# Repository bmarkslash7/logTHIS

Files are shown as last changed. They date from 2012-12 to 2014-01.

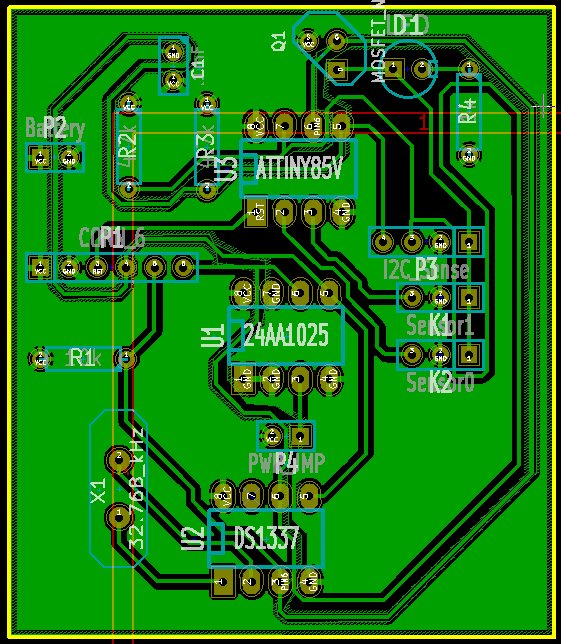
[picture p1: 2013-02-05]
schematic/logTHIS_pcb.jpg

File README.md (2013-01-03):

logTHIS
=======

Schematics and code for logTHIS, a low-powered datalogger for Temperature, Humidity and Irradiance Sensors.

Christopher Stieha: stieha at hotmail dot com

Abram Connelly: abetusk at gmail dot com

We are debating the CERN Open Hardware 1.1 licence (see ohwr.org/projects/cernohl/wiki) or the Creative Commons Attribution Share-Alike license (ala Arduino).

0------------------------------------------------

I2C functions are from http://www.instructables.com/id/I2C_Bus_for_ATtiny_and_ATmega/

0------------------------------------------------

The temperature and humidity sensor code is licensed under the GNU Lesser General Public License version 2.1.  
We stripped down the code available at http://nethoncho.com/arduino/DHT22/

From nethoncho.com:
  DHT22.cpp - DHT22 sensor library
  Developed by Ben Adams - 2011

  This library is free software; you can redistribute it and/or
  modify it under the terms of the GNU Lesser General Public
  License as published by the Free Software Foundation; either
  version 2.1 of the License, or (at your option) any later version.

  This library is distributed in the hope that it will be useful,
  but WITHOUT ANY WARRANTY; without even the implied warranty of
  MERCHANTABILITY or FITNESS FOR A PARTICULAR PURPOSE.  See the GNU
  Lesser General Public License for more details.

  You should have received a copy of the GNU Lesser General Public
  License along with this library; if not, write to the Free Software
  Foundation, Inc., 51 Franklin St, Fifth Floor, Boston, MA  02110-1301  USA

0------------------------------------------------

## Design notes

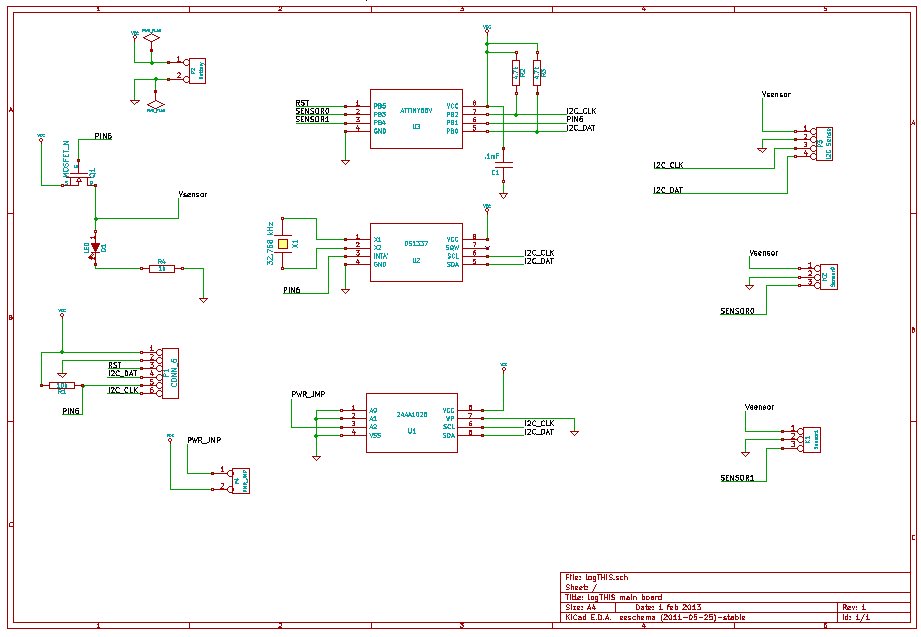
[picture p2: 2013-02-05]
schematic/logTHIS_schematic.jpg

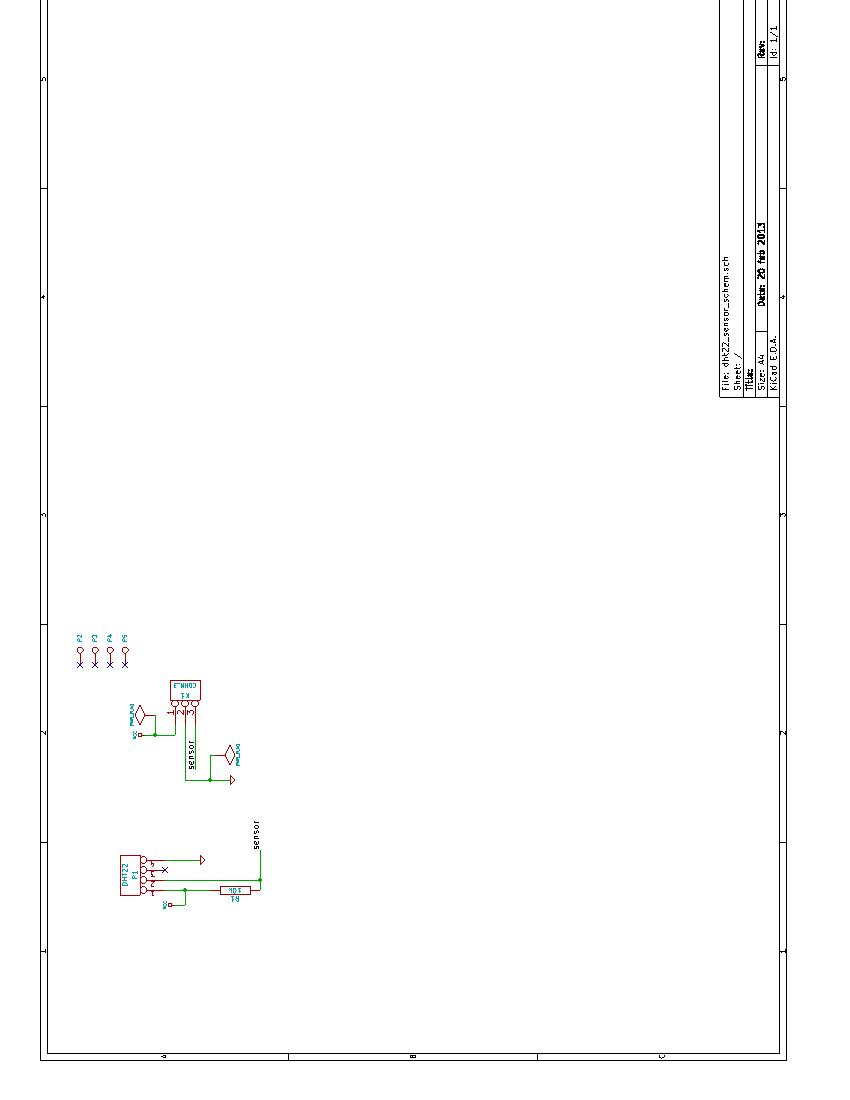
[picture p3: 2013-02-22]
pcb/dht22_sensor_schem/dht22_sensor_schematic.jpg

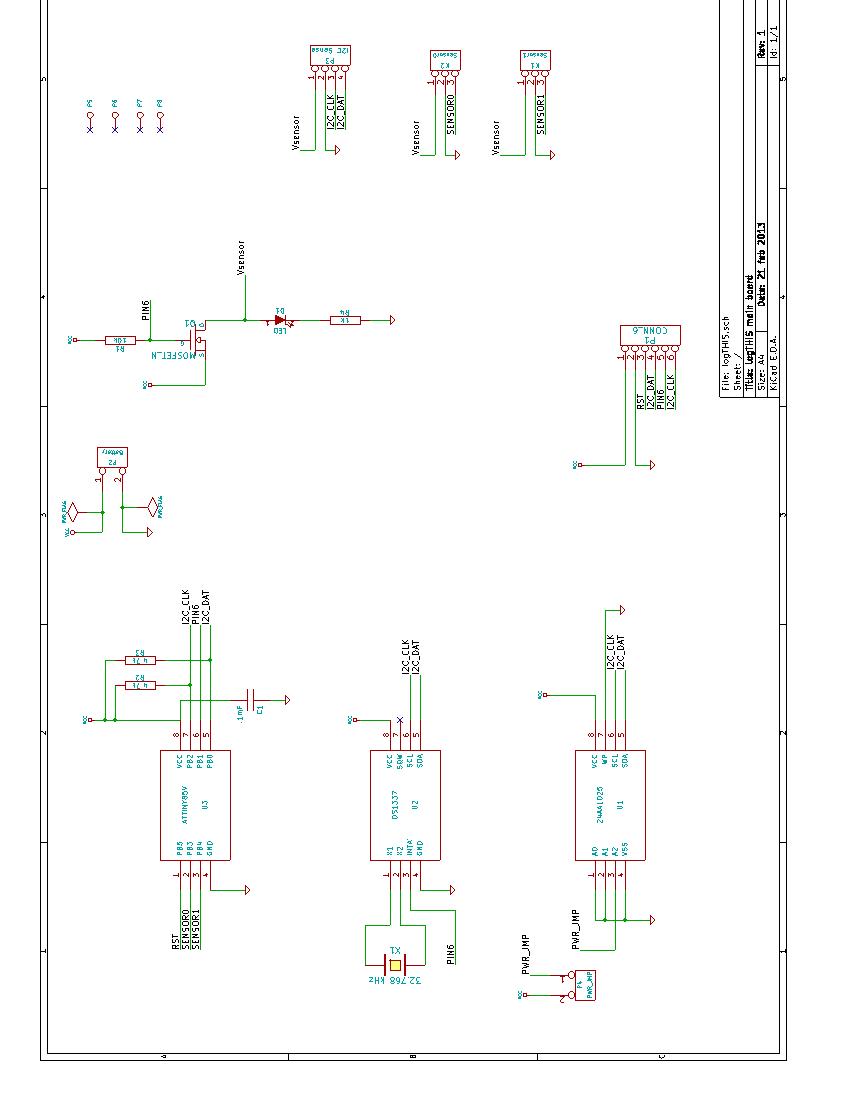
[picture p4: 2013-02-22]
pcb/logTHIS/logTHIS_schematic.jpg

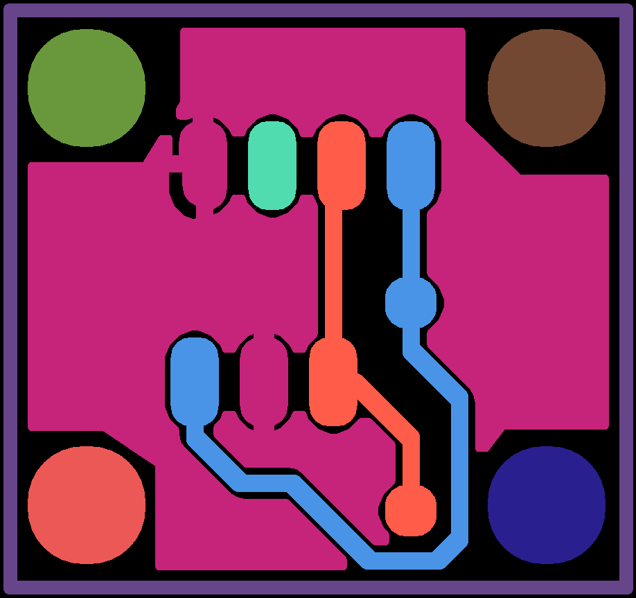
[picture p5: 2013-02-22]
pcb/gcode/dht22_sensor_schem/outp2_traced.png

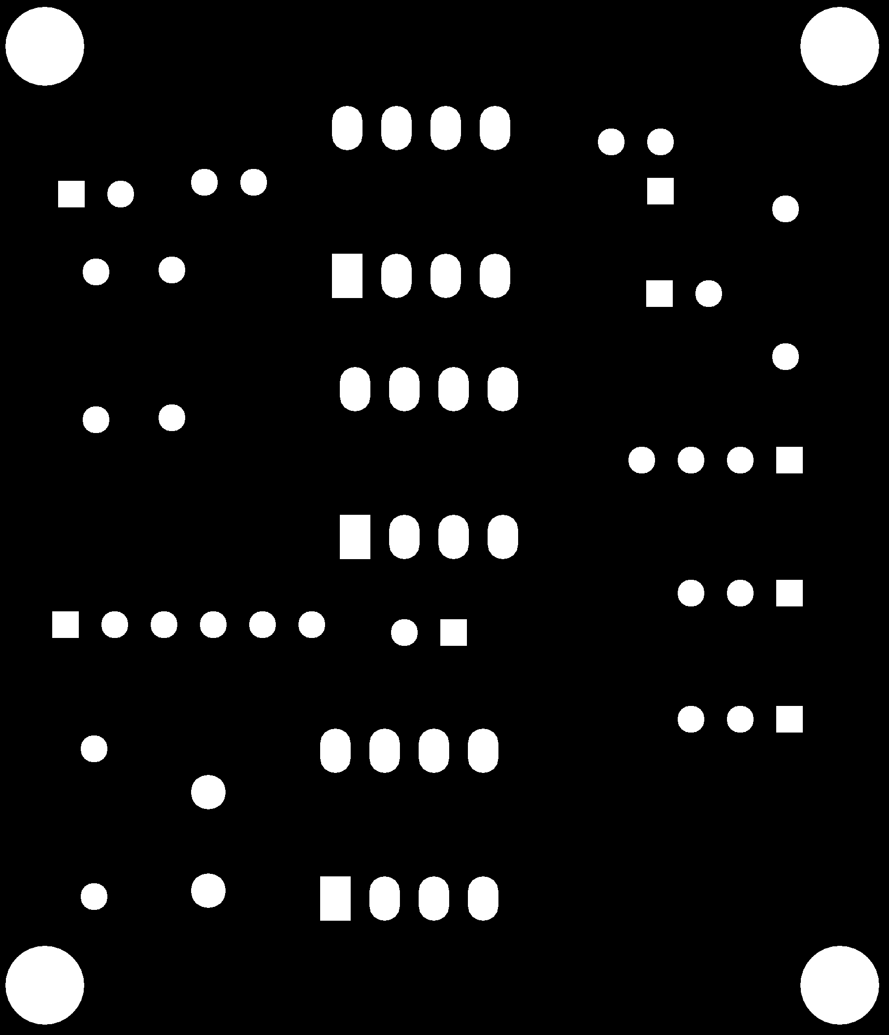
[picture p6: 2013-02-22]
pcb/gcode/logTHIS/outp1_original_front.png

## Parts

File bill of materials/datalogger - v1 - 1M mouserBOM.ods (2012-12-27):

mouser part number | quantity 1 | Mfg Part Number | Mfg Name | Mouser Part Number | Description | Price 1 | Min\Mult | Stock | Lead Time | Lifecycle | NCNR | RoHS | Suggested Replacement | RoHS Replacement | PB Free | Package Type | Package Quantity | Package Price | Data Sheet URL | Product Image
556-ATTINY85V10PU | 1 | ATTINY85V-10PU | Atmel | 556-ATTINY85V10PU | 8-bit Microcontrollers - MCU 8-bit Microcontrollers - MCU 8kB Flash 0.512kB EEPROM 6 I/O Pins | $2.26 | 1\1 | 2,355 | 6 Weeks |  | No | Yes
700-DS1337 | 1 | DS1337+ | Maxim Integrated | 700-DS1337 | Real Time Clock Real Time Clock I2C Serial RTC | $2.58 | 1\1 | 132 | 3 Weeks |  | No | Yes
579-24AA1025-I/P | 1 | 24AA1025-I/P | Microchip | 579-24AA1025-I/P | EEPROM EEPROM 1M | $3.65 | 1\1 | 106 |  |  |  | Yes
579-24AA32A-I/P | 1 | 24AA32A-I/P | Microchip | 579-24AA32A-I/P | EEPROM EEPROM 4kx8 | $0.50 | 1\1 | 918 |  |  | No | Yes
522-ZVP3306A | 1 | ZVP3306A | Diodes Inc. | 522-ZVP3306A | MOSFET MOSFET P-Chnl 60V | $0.64 | 1\1 | 3,572 |  |  | No | Yes
732-C002RX32.76K-EPB | 1 | C-002RX 32.7680K-E:PBFREE | Epson | 732-C002RX32.76K-EPB | Crystals Crystals 32.768KHz 6.0pF 20ppm -10C +60C | $0.32 | 1\1 | 6,623 | 6 Weeks |  | No | Yes

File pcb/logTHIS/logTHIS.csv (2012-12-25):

Id | Designator | Package | Quantity | Designation | Supplier and ref
1 | Q1 | TO92DGS | 1 | MOSFET_N
2 | P1 | SIL-6 | 1 | CONN_6
3 | P3 | SIL-4 | 1 | I2C_Sense
4 | K2 | SIL-3 | 1 | Sensor0
5 | K1 | SIL-3 | 1 | Sensor1
6 | P2 | SIL-2 | 1 | Battery
7 | D1 | LEDV | 1 | LED
8 | U3 | DIP-8__300_ELL | 1 | ATTINY85V
9 | U1 | DIP-8__300_ELL | 1 | 24AA1025
10 | U2 | DIP-8__300_ELL | 1 | DS1337
11 | C1 | C1 | 1 | .1mF
12 | R1 | R3 | 1 | 10k
13 | R2,R3 | R3 | 2 | 4.7k
14 | R4 | R3 | 1 | 1k
15 | X1 | HC-18UV | 1 | 32.768_kHz

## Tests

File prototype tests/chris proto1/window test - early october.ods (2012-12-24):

 |  | light1 |  |  | light2 |  |  | temp |  |  | humidity |  | time(backwards) | time(backwards)
0 | 14CA | 5322 | 2 | 498 | 1176 | 4 | CA | 202 | 6 | 222 | 546 | 8 | 2 | 2
10 | 9AB | 2475 | 12 | 21A | 538 | 14 | CD | 205 | 16 | 229 | 553 | 18 | 3002 | 12290
20 | 2A8 | 680 | 22 | 96 | 150 | 24 | DB | 219 | 26 | 212 | 530 | 28 | 3 | 3
30 | 458 | 1112 | 32 | EF | 239 | 34 | E9 | 233 | 36 | 1F7 | 503 | 38 | 3003 | 12291
40 | 4D1 | 1233 | 42 | 106 | 262 | 44 | F3 | 243 | 46 | 1E3 | 483 | 48 | 4 | 4
50 | 88D | 2189 | 52 | 1DE | 478 | 54 | F6 | 246 | 56 | 1EE | 494 | 58 | 3004 | 12292
60 | F2F | 3887 | 62 | 34F | 847 | 64 | F3 | 243 | 66 | 1FF | 511 | 68 | 5 | 5
70 | C83 | 3203 | 72 | 2C1 | 705 | 74 | EF | 239 | 76 | 1FF | 511 | 78 | 3005 | 12293
80 | 5F5 | 1525 | 82 | 14A | 330 | 84 | EF | 239 | 86 | 1F5 | 501 | 88 | 6 | 6
90 | 9BA | 2490 | 92 | 21C | 540 | 94 | F2 | 242 | 96 | 1EB | 491 | 98 | 3006 | 12294
100 | 990 | 2448 | 102 | 214 | 532 | 104 | F1 | 241 | 106 | 1EC | 492 | 108 | 7 | 7
110 | 931 | 2353 | 112 | 203 | 515 | 114 | F1 | 241 | 116 | 1F2 | 498 | 118 | 3007 | 12295
120 | 138A | 5002 | 122 | 456 | 1110 | 124 | EF | 239 | 126 | 1FF | 511 | 128 | 8 | 8
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

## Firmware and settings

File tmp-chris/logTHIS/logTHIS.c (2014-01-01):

/*********************************************
ver2 of datalogger:
Wake up from alarm from RTC once a minute
Determine whether uC needs to collect data
Read from Humidity sensor (keep trying a couple of times if initial fails
Read from Light sensor - convert cap sensor to ADC
Write data to EEPROM
Put AVR to sleep
 * Author: christopher stieha
 * Filename: logTHIS.c
 * Chip: ATtiny85

I2c code from http://www.instructables.com/id/I2C_Bus_for_ATtiny_and_ATmega/ user doctek
HUMIDITY code modified from https://github.com/nethoncho/Arduino-DHT22 user nethoncho
 */
// From http://playground.arduino.cc/Main/AVR 
// use this to clear bits
#ifndef cbi
#define cbi(sfr, bit) (_SFR_BYTE(sfr) &= ~_BV(bit))
#endif
// Use this to set bits
#ifndef sbi
#define sbi(sfr, bit) (_SFR_BYTE(sfr) |= _BV(bit))
#endif 

#define F_CPU 1000000
#include <avr/io.h>
#include <util/delay.h>
#include <inttypes.h>
#include <stdint.h>
#include <avr/interrupt.h>
#include <avr/eeprom.h>
#include <avr/sleep.h>
#include "USI_TWI_Master.h"

// PIN DEFINITIONS
#define PAR_SENSOR 3
#define HUMIDITY 4
#define HUMIDITY_CLOCK_TIME 6		// number compared to timing of humidity sensors to determine 0 or 1
					// changes with the speed of the processor
#define DISPLAY_LED 4

// EEPROM definitions
// #define MEMORY_ADDR  0b1010		// function needs to <<4  add BLOCK (0,1) add Chip select (two bits), and R/W 
#define MEMORY_ADDR  0b1010000		// 32kb EEPROM
#define MESSAGEBUF_SIZE       9

// RTC definitions
#define RTC_ADDR 0b1101000		// function needs to <<1 and add R/W bit

#define HOW_OFTEN 2			// 0 is every minute, 1 is once an hour, 2 is twice an hour, 
							// 4 is 4 times and hour, 6 is 6 times an hour

#define DHT22_ERROR_VALUE -99.5

// This should be 40, but the sensor is adding an extra bit at the start
#define DHT22_DATA_BIT_COUNT 41


// FUNCTION DECLARATIONS
int set_PORTB_bit (int position, int value);
int set_DDRB_bit (int position, int value);
uint16_t readPAR_Sensor (int pinPAR_SENSOR);
uint16_t readPAR_SensorADC (int pinPAR_SENSOR);
uint16_t readPAR_SensorCAPADC (int pinPAR_SENSOR);
int set_RTC_bit (uint8_t device, uint8_t address, uint8_t bit, uint8_t value);


// ------------------HERE STARTS MAIN ----------------------------------------------
int main (void)
{
// configure sleep state and interrupt pin
//	cli();
	set_sleep_mode(SLEEP_MODE_PWR_DOWN);	
	
	
// blink on and off to say it is on and working
	set_DDRB_bit(6,1);
	// Blink DISPLAY_LED on and off to show that it has started
	int blinki;
	for (blinki = 0; blinki<10; blinki++) {
		set_PORTB_bit(6,1);  // sets B0 as high
		_delay_ms(200);
		set_PORTB_bit(6,0); // sets B0 as low
		_delay_ms(200);
	}
	set_DDRB_bit(6,0);
// -------------------------------------------
	
//        sbi(GIMSK, 5);
	GIMSK |= (1 << 5);	// enable interrupts
	PCMSK |= (1 << 1);	// set Pin6/PB1/PCINT1 as interupt pin
				// currently same as DISPLAY_LED

// initialize pins
	USI_TWI_Master_Initialise();
	set_DDRB_bit(PAR_SENSOR,1);
	set_DDRB_bit(HUMIDITY,1);
	set_DDRB_bit(DISPLAY_LED,1);

// initialize variables
	uint16_t externaleepromcounter = 0;
//	uint16_t internaleepromcounter = 0;
	int i;
	
	int16_t currentHumidity;
	int16_t currentTemperature;

	// data for the humidity sensor
// 	int16_t currentHumidity;
//	int16_t currentTemperature;
//	uint32_t outputFromHumidityAndTemperature;
	// end of data for humidity sensor

_delay_ms(10000);

// write internalEEPROM to 0 to represent 0 bank of externalEEPROM
// TODO: THIS MAY NOT BE THE PLACE TO DO THIS, AS IF BATTERY RESET, THEN OVERWRITES DATA
	eeprom_write_byte( (uint8_t*) 1, 0);

/* -----------------------------------------
// Blink DISPLAY_LED on and off to show that it has started
	int i;
	for (i = 0; i<10; i++) {
		set_PORTB_bit(DISPLAY_LED,1);  // sets B0 as high
		_delay_ms(200);
		set_PORTB_bit(DISPLAY_LED,0); // sets B0 as low
		_delay_ms(200);
	}
// -------------------------------------------
*/

// write alarm to RTC for once per minute
//	_delay_ms(1000);			// If blinky light above remains, not required
//	set_RTC_bit(RTC_ADDR, 0x0E, 2, 1); //sets inct flag


  	set_RTC_bit(RTC_ADDR, 0x0E, 1, 1);		// set A1IE bit to 1, enable alarm

	// tells alarm to activate every minute on the 00 second mark
	set_RTC_bit(RTC_ADDR, 0x0D, 7, 1);	// set A2M4 bit to 1, 
	set_RTC_bit(RTC_ADDR, 0x0C, 7, 1);	// set A2M3 bit to 1
	set_RTC_bit(RTC_ADDR, 0x0B, 7, 1);	// set A2M2 bit to 1


// TURNED OFF ALARM SETTING 
/*
// set alarm 1
	set_RTC_bit(RTC_ADDR, 0x0E, 2, 1);		// set intcn bit to 1, enable alarm
	set_RTC_bit(RTC_ADDR, 0x0E, 0, 1);
	// tells alarm to activate every minute on the 00 second mark
	set_RTC_bit(RTC_ADDR, 0x08, 7, 1);	// set A2M4 bit to 1, 
	set_RTC_bit(RTC_ADDR, 0x09, 7, 1);	// set A2M3 bit to 1
	set_RTC_bit(RTC_ADDR, 0x0A, 7, 1);	// set A2M2 bit to 1
*/


// TODO: write initial time to beginning of externalEEPROM

// Begin while loop that will stop when externalEEPROM is full
//  EEPROM is full when both banks of 512kbits filled
	uint16_t basici;	// need to decide maximum number of measurements (128000 bytes/ info)
				// when 6 bytes of data, max points is 21333
				// when 8 bytes data, (sensors + hour + minute), max points is 16000
	uint16_t maxdata = 500; 	// magic number, be careful  


// ******************************************************************
// ------ BEGINNING OF LOOP THAT GOES AROUND AND AROUND -------------
// ******************************************************************

//	for (basici = 0; basici < (maxdata-8); basici++)
	for (;;)
	{ 	

// turn off interrupts
		cli();	
/*
  	USI_TWI_Master_Initialise();
	set_DDRB_bit(PAR_SENSOR,1);
	set_DDRB_bit(HUMIDITY,1);
	set_DDRB_bit(DISPLAY_LED,1);
*/
	set_DDRB_bit(PAR_SENSOR,1); 	// turn PAR_SENSOR into OUTPUT
	set_PORTB_bit(PAR_SENSOR,0);	// remove charge on capacitor on LED
	
	
	
// read time
	unsigned char temp;

  	uint8_t messageBuf[3];
	uint8_t timeBuf[3];
	messageBuf[0] = (RTC_ADDR << 1) | (0); 	// tell clock you are going to read it + W
	messageBuf[1] = 0x01; 			// write to clock where you want to read - minutes
	timeBuf[0] = (RTC_ADDR << 1) | (1);	// tell clock you are going to read it + R
	timeBuf[1] = 0xBE;
	timeBuf[2] = 0xEF;
	
	temp = USI_TWI_Start_Read_Write(messageBuf, 2);
	temp = USI_TWI_Start_Read_Write(timeBuf, 2);
	uint8_t minutes = timeBuf[1];		// saves minutes for later use
	uint8_t hours = 0;


	
// compare minute to determine if measurement needs to be taken

	int measurement_is_needed = 0;
	if   (HOW_OFTEN == 0) {measurement_is_needed = 1;}
	if ( (HOW_OFTEN == 1) && (minutes == 0) ) {measurement_is_needed = 1;}
	if ( (HOW_OFTEN == 2) && ( (minutes == 0) || (minutes == 0x30) ) ) {measurement_is_needed = 1;}
	if ( (HOW_OFTEN == 4) && ( (minutes == 0) || (minutes == 0x30) || (minutes == 0x15) || (minutes == 0x45) ) )
		{measurement_is_needed = 1;}
	if ( (HOW_OFTEN == 6) && ( (minutes==0) || (minutes==0x10) || (minutes==0x20) || (minutes==0x30) || (minutes==0x40) || (minutes==0x50) ) )
		{measurement_is_needed = 1;}



// ERROR CHECKING
//	measurement_is_needed = 1;
	_delay_ms(500);
	
// determine if a measurement is needed
	if (measurement_is_needed)
{
// Need to first collect hour measurements
// only done if measurement is needed!
	messageBuf[0] = (RTC_ADDR << 1) | (0); 	// tell clock you are going to read it + W
	messageBuf[1] = 0x02; 			// write to clock where you want to read - hours
	timeBuf[0] = (RTC_ADDR << 1) | (1);	// tell clock you are going to read it + R
	timeBuf[1] = 0xBE;
	timeBuf[2] = 0xEF;
	
	temp = USI_TWI_Start_Read_Write(messageBuf, 2);
	temp = USI_TWI_Start_Read_Write(timeBuf, 2);
	hours = timeBuf[1];
	
	
// Blink LED to show that it is taking a measurement
/* --------------------------------------------------------------
	_delay_ms(2000);
	for (i = 0; i<5; i++) {
		set_PORTB_bit(DISPLAY_LED,1);  // sets B0 as high
		_delay_ms(200);
		set_PORTB_bit(DISPLAY_LED,0); // sets B0 as low
		_delay_ms(200);
	}	
// ----------------------------------------------------------------
*/


// Take Light Measurements


/*
	// Turn on ADC
	ADCSRA |= (1<<ADEN);
	// set internal reference to 2.56V
	ADMUX |= (1<<REFS2);
	ADMUX |= (1<<REFS1);
	ADMUX &= ~(1<<REFS0);
	// set PAR_SENSOR as ADC
	ADMUX &= ~(1<<3); // clear MUX3
	ADMUX &= ~(1<<2); // clear MUX2
	ADMUX |= (PAR_SENSOR & 0b0010);
	ADMUX |= (PAR_SENSOR & 0b0001);
	
	_delay_ms(50);
	ADCSRA |= (1<<ADSC);
	while (ADCSRA & (1<<ADSC));
	_delay_ms(50);
	ADCSRA |= (1<<ADSC);
	while (ADCSRA & (1<<ADSC));
	
	uint16_t tempADCL = (uint16_t) ADCL;
	uint16_t tempADCH = (uint16_t) ADCH;
	
	// set flag to show we used 2.56V
	uint16_t PARdata = 0;
	PARdata = (tempADCH<<8) | (tempADCL);
	
	if (PARdata >= 440)
	{
		PARdata |= (0x8000);
	}
// if voltage is lower than 1.1V, we can change the reference to get a better measurement
	if (PARdata < 440)
	{
		ADMUX &= ~(1<<REFS2);
		_delay_ms(50);
		ADCSRA |= (1<<ADSC);
		while (ADCSRA & (1<<ADSC));
		_delay_ms(50);
		ADCSRA |= (1<<ADSC);
		while (ADCSRA & (1<<ADSC));
		
		tempADCL = (uint16_t) ADCL;
		tempADCH = (uint16_t) ADCH;
		PARdata = 0;
		PARdata = (tempADCH<<8) | (tempADCL);
	}
	
	// Turn off ADC
	ADCSRA &= ~(1<<ADEN);
	
*/	
	
// take light measurements - Capacitive Sensing
		uint16_t PARdata = readPAR_Sensor(PAR_SENSOR);

//		uint16_t PARdataADC = 0;
//		uint16_t PARdataADC = readPAR_SensorADC(PAR_SENSOR);

		uint16_t PARdataCAPADC = readPAR_SensorCAPADC(PAR_SENSOR);


//ERROR CHECKING		
//	set_DDRB_bit(PAR_SENSOR,1); 	// turn PAR_SENSOR into OUTPUT
//	set_PORTB_bit(PAR_SENSOR,0);	// remove charge on capacitor on LED

/* ---------------------------------------------------------------------
// take humidity measurement, repeat if needed
// Initialize Humidity sensor
	_delay_ms(2000);	// Humidity sensor needs 2 seconds to wake up
	uint32_t outputFromHumidityAndTemperature = 0;	
	int humiditycounter = 0;
	currentHumidity = 0;
	currentTemperature = 0;
	while (outputFromHumidityAndTemperature == 0)
	{
	// Measure humidity and temperature

// BLINK THE LED FOR HUMIDITY MEASUREMENTS
	for (i = 0; i<5; i++) {
		set_PORTB_bit(DISPLAY_LED,1);  // sets B0 as high
		_delay_ms(500);
		set_PORTB_bit(DISPLAY_LED,0); // sets B0 as low
		_delay_ms(500);
	}	

		outputFromHumidityAndTemperature = readHumidityAndTemperatureSensor(HUMIDITY);
		currentHumidity = 0x0000FFFF & outputFromHumidityAndTemperature;
		currentTemperature = (outputFromHumidityAndTemperature >> 16) & 0x0000FFFF;

		if (outputFromHumidityAndTemperature != 0) {break;}	// Humidity has been measured, get out of here
		// If we have tested humidity 4 times, humidity is broken and we need to go on with life
		currentHumidity = 0xEEFF;
		currentTemperature = 0xEEFF;
		if (humiditycounter == 5) {break;}
		humiditycounter++;	
		_delay_ms(2000);	// Humidity sensor needs 2 seconds between readings
	}
//----------------------------------------------------------------------
*/

int humiditytemperaturecheck = 0;
int humtempcounter = 0;



// data for the humidity sensor
	uint8_t retryCount;
	uint8_t bitTimes[DHT22_DATA_BIT_COUNT];

	uint8_t checkSum, csPart1, csPart2, csPart3, csPart4;
	int humidityerrorcode = 0;
// end of data for humidity sensor
// !!!!!!!!!!!!!!!!!!!!!!!!!!!!!!!!!!!!!!!!!!!!!!!!!!!!!!!!!!!!!!!!!!!!!!!!
// BEGINNING OF HUMIDITY SENSOR
// !!!!!!!!!!!!!!!!!!!!!!!!!!!!!!!!!!!!!!!!!!!!!!!!!!!!!!!!!!!!!!!!!!!!!!!!
while (humiditytemperaturecheck == 0)
{
	_delay_ms(2000);
	
		currentHumidity = 0;
 		currentTemperature = 0;
 		checkSum = 0;
		humidityerrorcode = 0;

// clear out all the bittimes
		for(i = 0; i < DHT22_DATA_BIT_COUNT; i++)
		{
    			bitTimes[i] = 0;
		}

// activate signal by dropping data line to LOW
// will have to change to use my functions
// and get rid of reg and bitmask
	cli();
	//CONVERT PIN TO OUTPUT
	// WRITE PIN AS LOW
  set_DDRB_bit(HUMIDITY,1);	//DIRECT_WRITE_LOW(reg, bitmask);
  set_PORTB_bit(HUMIDITY,0);	//DIRECT_MODE_OUTPUT(reg, bitmask); // Output Low
  sei();
  _delay_us(1100); // 1.1 ms

  cli();
  // CONVERT PIN TO INPUT
  // IN ORDER TO READ DATA
  set_DDRB_bit(HUMIDITY,0);//DIRECT_MODE_INPUT(reg, bitmask);	// Switch back to input so pin can float
  sei();
  
  // wait for sensor to respond
  // Find the start of the ACK Pulse
  retryCount = 0;
  do
  {
    if (retryCount > 25) //(Spec is 20 to 40 us, 25*2 == 50 us)
    {
      humidityerrorcode = 1; //DHT_ERROR_NOT_PRESENT;
	break;
    }
    retryCount++;
    _delay_us(2);
  } while(!(PINB & (1 << HUMIDITY)));
 // Find the end of the ACK Pulse
  retryCount = 0;
  do
  {
    if (retryCount > 50) //(Spec is 80 us, 50*2 == 100 us)
    {
      humidityerrorcode = 1;//DHT_ERROR_ACK_TOO_LONG;
	break;
    }
    retryCount++;
    _delay_us(2);
  } while((PINB & (1 << HUMIDITY)));

// Once all hands are shaken, begin transfering data from humidity sensor to mcu
 // Read the 40 bit data stream
  for(i = 0; i < DHT22_DATA_BIT_COUNT; i++)
  {
    // Find the start of the sync pulse
	// each bit starts with a 50us LOW followed by a 70us bit
    retryCount = 0;
    do
    {
      if (retryCount > 70) //(Spec is 50 us, 35*2 == 70 us)
      {
        humidityerrorcode = 1;//DHT_ERROR_SYNC_TIMEOUT;
	break;      
	}
      retryCount++;
      _delay_us(1);
    } while(!(PINB & (1 << HUMIDITY)));
    // Measure the width of the data pulse
    retryCount = 0;
    do
    {
      if (retryCount > 100) //(Spec is 80 us, 50*2 == 100 us)
      {
        humidityerrorcode = 1;//DHT_ERROR_DATA_TIMEOUT;
	break;      
	}
      retryCount++;
      _delay_us(1);
    } while((PINB & (1 << HUMIDITY)));
    bitTimes[i] = retryCount;
  }
  // Now bitTimes have the number of retries (us *2)
  // that were needed to find the end of each data bit
  // Spec: 0 is 26 to 28 us
  // Spec: 1 is 70 us
  // bitTimes[x] <= 11 is a 0
  // bitTimes[x] >  11 is a 1
  // Note: the bits are offset by one from the data sheet, not sure why
  for(i = 0; i < 16; i++)
  {
    if(bitTimes[i + 1] > HUMIDITY_CLOCK_TIME)
    {
      currentHumidity |= (1 << (15 - i));
	bitTimes[i+1] = 1;
    }	else { bitTimes[i+1] = 0; }
	
  }
  for(i = 0; i < 16; i++)
  {
    if(bitTimes[i + 17] > HUMIDITY_CLOCK_TIME)
    {
      currentTemperature |= (1 << (15 - i));
	bitTimes[i + 17] = 1;
    }	else { bitTimes[i+17] = 0; }
  }
  for(i = 0; i < 8; i++)
  {
    if(bitTimes[i + 33] > HUMIDITY_CLOCK_TIME)
    {
      checkSum |= (1 << (7 - i));
	bitTimes[i+33] = 1;
    }	else { bitTimes[i+33] = 0; }
  }
  
  // This is the checksum part for error checking
  // make sure the right values were read
  csPart1 = currentHumidity >> 8;
  csPart2 = currentHumidity & 0xFF;
  csPart3 = currentTemperature >> 8;
  csPart4 = currentTemperature & 0xFF;
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
} // end int main (void)


// -------- BEGIN FUNCTIONS ----------------------------------------------------

ISR(PCINT0_vect) 
{
};

int set_RTC_bit (uint8_t device, uint8_t address, uint8_t bit, uint8_t value)
{
	uint8_t clockBuf[3];
	uint8_t tempBuf[3];
	unsigned char temp;			// var used in all read write situations to hold error throws

	// First need to tell RTC what address I want to read
	// then I need to request data in address from RTC
	// I then take data, add flag, and send it back
	clockBuf[0] = (device << 1) | (0); 	// tell clock you are going to talk to it + W
	clockBuf[1] = address; 			// tell clock you want to read alarm bit
	tempBuf[0] = (device << 1) | (1);
	tempBuf[1] = 0xFF;
	 
	temp = USI_TWI_Start_Read_Write(clockBuf, 2);
	temp = USI_TWI_Start_Read_Write(tempBuf, 2);


	//clockBuf[2] = clockBuf[1] | (1<<1);	//
	if (value == 0) {tempBuf[1] &= ~(1<<bit);}
	if (value == 1) {tempBuf[1] |= (1<<bit);}
	clockBuf[2] = tempBuf[1];

	temp = USI_TWI_Start_Read_Write(clockBuf, 3);
//	_delay_ms(10);

	return 1;
}

uint16_t readPAR_SensorADC (int pinPAR_SENSOR)
{
		int i;
	
// For PAR reading, we are going to take ten quick readings and then average
// this is based of capacitance sensing
		uint32_t PARaverage = 0;
		uint16_t returnPARdata = 0;		

	
		int j;
		
	// Turn on ADC
	ADCSRA |= (1<<ADEN);
	// set internal reference to 2.56V
	ADMUX |= (1<<REFS2);
	ADMUX |= (1<<REFS1);
	ADMUX &= ~(1<<REFS0);
	// get ready to set PAR_SENSOR as ADC
	ADMUX &= ~(1<<3); // clear MUX3
	ADMUX &= ~(1<<2); // clear MUX2
	// Change pin to ADC
	ADMUX |= (PAR_SENSOR & 0b0010);
	ADMUX |= (PAR_SENSOR & 0b0001);
	
	uint16_t tempADCL = 0;//(uint16_t) ADCL;
	uint16_t tempADCH = 0;//(uint16_t) ADCH;
	uint16_t PARdata = 0;
	uint16_t PARdatafinal= 0;
	
	
		for (j =0; j<10; j++) {
			// first remove residual charge on LED
			set_DDRB_bit(pinPAR_SENSOR,1); 	// turn PAR_SENSOR into OUTPUT
			set_PORTB_bit(pinPAR_SENSOR,0);	// remove charge on capacitor on LED
			_delay_ms(100);
			// charge up LED capacitor
			set_PORTB_bit(pinPAR_SENSOR,1);
			_delay_ms(100);	
			// set negPB3 to input
			set_DDRB_bit(pinPAR_SENSOR,0);
			// drop negPB3 to LOW		
			set_PORTB_bit(pinPAR_SENSOR,0);	
			
			// Turn on ADC
			ADCSRA |= (1<<ADEN);
			
			// Collect a measurement and throw out first measurement
				ADCSRA |= (1<<ADSC);
				while (ADCSRA & (1<<ADSC));
	//			tempADCL = (uint16_t) ADCL;
//				tempADCH = (uint16_t) ADCH;
				PARdata = (ADCL) | (ADCH<<8);
				

			
// First we wait until the LED measures right below 2.56V
// we then wait 5 ms and take another ADC measurement
// Then we record the difference between the two values
			// take another measurement
			ADCSRA |= (1<<ADSC);
			while (ADCSRA & (1<<ADSC));
			PARdata = (ADCL) | (ADCH<<8);
			while (PARdata > 1022)
			{
				ADCSRA |= (1<<ADSC);
				while (ADCSRA & (1<<ADSC));
				PARdata = (ADCL) | (ADCH<<8);
			}
			_delay_ms(5);
			ADCSRA |= (1<<ADSC);
			while (ADCSRA & (1<<ADSC));
			PARdatafinal = (ADCL) | (ADCH<<8);
			uint16_t tempPARdata = PARdata - PARdatafinal;
			PARaverage += (uint32_t) tempPARdata;
			
					// Turn off ADC
			ADCSRA &= ~(1<<ADEN);
			_delay_ms(100);
		} // end int i for loop
		
		PARaverage = (PARaverage/10);
		returnPARdata = (uint16_t) PARaverage;
		

		
		return(returnPARdata);
}


uint16_t readPAR_Sensor (int pinPAR_SENSOR)
{
// For PAR reading, we are going to take ten quick readings and then average
// this is based of capacitance sensing
		uint32_t PARaverage = 0;
		uint16_t returnPARdata = 0;		

		int i;
		int j;
		for (i =0; i<10; i++) {
			// first remove residual charge on LED
			set_DDRB_bit(pinPAR_SENSOR,1); 	// turn PAR_SENSOR into OUTPUT
			set_PORTB_bit(pinPAR_SENSOR,0);	// remove charge on capacitor on LED
			_delay_ms(100);
			// charge up LED capacitor
			set_PORTB_bit(pinPAR_SENSOR,1);
			_delay_ms(100);		

			// set negPB3 to input
			set_DDRB_bit(pinPAR_SENSOR,0);
			// drop negPB3 to LOW		
			set_PORTB_bit(pinPAR_SENSOR,0);		
		
			for (j=0; j<30000; j++) {
				if ((PINB & (1 << pinPAR_SENSOR) )==0) {break;}
			}
			PARaverage += (uint32_t) j;
			_delay_ms(100);
		} // end int i for loop
		
		PARaverage = (PARaverage/10);
		returnPARdata = (uint16_t) PARaverage;
		return(returnPARdata);
}



int set_PORTB_bit (int position, int value) 
{
	// taken from imakeprojects.com/Projects/avr-tutorial
	
	if (value ==0) { PORTB &= ~(1 << position); }
	else { PORTB |= (1 << position);}

	return 1;
}

int set_DDRB_bit (int position, int value)
{
	if (value==0) { DDRB &= ~(1<<position); }
	else { DDRB |= (1<<position); }
	return 1;
}

uint16_t readPAR_SensorCAPADC (int pinPAR_SENSOR)
{
		int i;
	
// For PAR reading, we are going to take ten quick readings and then average
// this is based of capacitance sensing
		uint32_t PARaverage = 0;
		uint16_t returnPARdata = 0;		

	
		int j;
		
	// Turn on ADC
	ADCSRA |= (1<<ADEN);
	// set internal reference to 2.56V
	ADMUX |= (1<<REFS2);
	ADMUX |= (1<<REFS1);
	ADMUX &= ~(1<<REFS0);
	// get ready to set PAR_SENSOR as ADC
	ADMUX &= ~(1<<3); // clear MUX3
	ADMUX &= ~(1<<2); // clear MUX2
	// Change pin to ADC
	ADMUX |= (PAR_SENSOR & 0b0010);
	ADMUX |= (PAR_SENSOR & 0b0001);
	
	uint16_t tempADCL = 0;//(uint16_t) ADCL;
	uint16_t tempADCH = 0;//(uint16_t) ADCH;
	uint16_t PARdata = 0;
	uint16_t PARdatafinal= 0;
	
	
		for (i =0; i<10; i++) {
			// first remove residual charge on LED
			set_DDRB_bit(pinPAR_SENSOR,1); 	// turn PAR_SENSOR into OUTPUT
			set_PORTB_bit(pinPAR_SENSOR,0);	// remove charge on capacitor on LED
			_delay_ms(100);
			// charge up LED capacitor
			set_PORTB_bit(pinPAR_SENSOR,1);
			_delay_ms(100);	
			// set negPB3 to input
			set_DDRB_bit(pinPAR_SENSOR,0);
			// drop negPB3 to LOW		
			set_PORTB_bit(pinPAR_SENSOR,0);	
			
			// Turn on ADC
			ADCSRA |= (1<<ADEN);
			
			// Collect a measurement and throw out first measurement
				ADCSRA |= (1<<ADSC);
				while (ADCSRA & (1<<ADSC));
	//			tempADCL = (uint16_t) ADCL;
//				tempADCH = (uint16_t) ADCH;
				PARdata = (ADCL) | (ADCH<<8);
					
			// we wait until ADC reads just below 2.56V then we switch
			// back to capacitance measuring and time how long before we
			// get digital zero


			// take another measurement
			ADCSRA |= (1<<ADSC);
			while (ADCSRA & (1<<ADSC));
			PARdata = (ADCL) | (ADCH<<8);
			while (PARdata > 1022)
			{
				ADCSRA |= (1<<ADSC);
				while (ADCSRA & (1<<ADSC));
				PARdata = (ADCL) | (ADCH<<8);
			}
			
			// now we measure until pin is digital zero
			// Turn off ADC
			ADCSRA &= ~(1<<ADEN);
			
			for (j=0; j<30000; j++) {
				if ((PINB & (1 << pinPAR_SENSOR) )==0) {break;}
			}
			PARaverage += (uint32_t) j;
		
					
			_delay_ms(100);
		} // end int i for loop
		
		PARaverage = (PARaverage/10);
		returnPARdata = (uint16_t) PARaverage;
		return(returnPARdata);
}

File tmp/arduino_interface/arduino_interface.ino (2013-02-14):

#include <Wire.h>

#include "menu_system.h"

//#define EEPROM_32K
#define EEPROM_1M


#define EEPROM_I2C_ADDR0 0x50
#ifdef EEPROM_1M
  #define EEPROM_I2C_ADDR1 0x54 
#endif

#ifdef EEPROM_1M
  #define MAXADDRESS_foo 64000
#elif defined EEPROM_32K
  #define MAXADDRESS_foo 4000
#endif

#define RTC_I2C_ADDR 0x68


//#define MAXADDRESS 4096
#define MAXADDRESS 240



unsigned int holder = 0;
int counter = 0;

byte readEEPROM(int deviceaddress, unsigned int eeaddress ) {
  byte rdata = 0xFF;

  Wire.beginTransmission(deviceaddress);
  Wire.write((int)(eeaddress >> 8)); // MSB
  Wire.write((int)(eeaddress & 0xFF)); // LSB
  Wire.endTransmission();

  Wire.requestFrom(deviceaddress,1);

  if (Wire.available()) rdata = Wire.read();
  return rdata;
}


void read_eeprom()
{

  unsigned int address = 0;
  uint8_t b, bank_n=1;

#ifdef EEPROM_1M
  uint8_t bank[2] = { EEPROM_I2C_ADDR0, EEPROM_I2C_ADDR1 };
  bank_n = 2;
#elif defined EEPROM_32K
  uint8_t bank[1] = { EEPROM_I2C_ADDR0 };
#endif

  // only needs to be done once...redundant...
  Wire.begin();

  for (b=0; b < bank_n; b++)
    for (address = 0; address < (MAXADDRESS); address+=2) {
      Serial.print("[");
      Serial.print(address);
      Serial.print("] ");
      holder = ( (readEEPROM(bank[b], address)& 0xFF) << 8);
      holder |= (readEEPROM(bank[b], (address+1)) & 0xFF);
      Serial.print("0x");
      Serial.print(holder, HEX);
      Serial.print(" ");
      Serial.print(holder,DEC);
      Serial.print(" ");
      counter++;

      if ((counter == 5)) { Serial.println(); counter = 0;}
      else { Serial.print("  "); }

    }

  Serial.write("\r\n");
}

void clear_eeprom()
{
  unsigned int address = 0;
  uint8_t b, bank_n=1;

#ifdef EEPROM_1M
  uint8_t bank[2] = { EEPROM_I2C_ADDR0, EEPROM_I2C_ADDR1 };
  bank_n = 2;
#elif defined EEPROM_32K
  uint8_t bank[1] = { EEPROM_I2C_ADDR0 };
#endif

  // only needs to be done once...redundant...
  Wire.begin();

  for (b =0; b < bank_n; b++) 
  {
    Wire.beginTransmission( bank[b] );

    // start at 0
    Wire.write(0);
    Wire.write(0);

    // write with all 0xff
    for (address = 0; address < MAXADDRESS; address++)
      Wire.write(0xff);

    Wire.endTransmission();
  }


}

float convert_temperature(byte byt0, byte byt1)
{
  float f;
  f = byt0 & 0x7F;
  f *= 256;
  f += byt1;
  f /= 10;
  if (byt0 & 0x80)
    f *= -1;
  return f;
}


float convert_humidity(byte byt0, byte byt1)
{
  float f;
  f = byt0;
  f *= 256;
  f += byt1;
  f /= 10;
  return f;
}


void read_eeprom_pretty(void)
{
  char tbuf[128];
  byte byt0, byt1;
  float f;
  unsigned int address = 0;
  uint8_t b, bank_n=1;

#ifdef EEPROM_1M
  uint8_t bank[2] = { EEPROM_I2C_ADDR0, EEPROM_I2C_ADDR1 };
  bank_n = 2;
#elif defined EEPROM_32K
  uint8_t bank[1] = { EEPROM_I2C_ADDR0 };
#endif


  // only needs to be done once...redundant...
  Wire.begin();

  for (b=0; b < bank_n; b++)
  {
    for (address = 0; address < MAXADDRESS; address += 10)
    {
      sprintf(tbuf, "[%x:%4x] ", 0, address);
      Serial.write(tbuf);

      // HH:MM
      byt1 = readEEPROM(bank[b], address) & 0xff;
      byt0 = readEEPROM(bank[b], address+1) & 0xff;
      Serial.print(byt0, DEC);
      Serial.write(":");
      Serial.print(byt1, DEC);
      //Serial.write(tbuf);

      // PAR
      byt0 = readEEPROM(bank[b], address+2);
      byt1 = readEEPROM(bank[b], address+3);
      sprintf(tbuf, " PAR(%x,%x)", byt0, byt1);
      Serial.write(tbuf);

      // PAR CAP
      byt0 = readEEPROM(bank[b], address+4);
      byt1 = readEEPROM(bank[b], address+5);
      sprintf(tbuf, " CAP(%x,%x)", byt0, byt1);
      Serial.write(tbuf);

      // Temp
      f = convert_temperature(
            readEEPROM(bank[b], address+4),
            readEEPROM(bank[b], address+5) );
      sprintf(tbuf, " T(%f C)", (double)f);
      Serial.write(tbuf);

      // Humidity
      f = convert_humidity(
            readEEPROM(bank[b], address+4),
            readEEPROM(bank[b], address+5) );
      sprintf(tbuf, " Hum(%f)", (double)f);
      Serial.write(tbuf);

      Serial.write("\r\n");
    }
  }

}

void read_rtc_date()
{
  uint8_t i;
  byte byt;

  Serial.write("\n\r");

  // redundant
  Wire.begin();

  Wire.beginTransmission(RTC_I2C_ADDR);
  Wire.write(0);
  Wire.endTransmission();
  Wire.requestFrom(RTC_I2C_ADDR,16);

  for (i=0; i<16; i++)
  {
    if (Wire.available()) 
    {
      byt = Wire.read();
      Serial.print(byt);

      if (i == 8) 
        Serial.write("\n\r");
    }
  }

}

void read_rtc_date_pretty()
{
  uint8_t i;
  byte byt;

  Serial.write("\n\r");

  // redundant
  Wire.begin();

  Wire.beginTransmission(RTC_I2C_ADDR);
  Wire.write(0);
  Wire.endTransmission();
  Wire.requestFrom(RTC_I2C_ADDR,16);
  for (i=0; i<16; i++)
  {
    if (Wire.available()) 
    {
      byt = Wire.read();
      Serial.print(byt, HEX);
      Serial.write(" ");

      if (i == 8) 
        Serial.write("\n\r");
    }
  }

}


void set_rtc_date(byte sec, byte min, byte hour, byte day, byte date, int year)
{
  byte year_l = 0xff, year_h = 0xff;
  Serial.write("set_rtc_date not implemnted\r\n");

  // redundant
  Wire.begin();

  //DOES NOT WORK
  // just a placeholder for now
  Wire.beginTransmission(RTC_I2C_ADDR);
  Wire.write(0);
  Wire.write(sec);
  Wire.write(min);
  Wire.write(hour);
  Wire.write(day);
  Wire.write(date);
  Wire.write(year_h);
  Wire.write(year_l);
  Wire.endTransmission();

}

void setup() {
  // initialize serial:
  Serial.begin(9600);
  Serial.write("$ ");
  cmd_init();
}

void loop() {
  char byt;

  // if there's any serial available, read it:
  while (Serial.available() > 0) {
    byt = Serial.read();
    cmd_process(byt);
  }

}


//------------------------ menu system



cmd_t cmd = {0};

void cmd_history_commit()
{
  int i, j, k, pos;

  // get destination position into static history to copy
  // current command into
  pos = ( cmd.history_start + cmd.history_n ) % CMD_HISTORY_LEN;
  if ( cmd.history_n < CMD_HISTORY_LEN )
    cmd.history_n ++;

  if (cmd.history_n == CMD_HISTORY_LEN)
    cmd.history_start = (cmd.history_start + 1) % CMD_HISTORY_LEN;

  // copy current command into static history
  k = cmd.history_scratch_pos;
  for (i=0; i < CMD_BUF_LEN; i++)
    cmd.history[ pos ][i] = cmd.history_scratch[ k ][i];

  // copy static history into scratch
  for (i=0; i < CMD_HISTORY_LEN; i++)
    for (j=0; j < CMD_BUF_LEN; j++)
      cmd.history_scratch[i][j] = cmd.history[i][j];

  // update scratch position
  cmd.history_scratch_pos = (cmd.history_start + cmd.history_n) % CMD_HISTORY_LEN;

  // keep buf as our pointer to our active command line to simplify things
  cmd.buf = cmd.history_scratch[ cmd.history_scratch_pos ];
  cmd.buf[0] = '\0';
  cmd.buf_pos = 0;
  cmd.buf_n = 0;


  Serial.write("$ ");

}
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

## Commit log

2012-12-23 added arduino code
2012-12-24 uploading information
    [datalogger - v1 - 32k mouserBOM.xls, logTHIS.brd, logTHIS.sch]
2012-12-24 including logger code currently on prototype1
    [window test - early october.ods]
2012-12-25 Removed save directory. We're under a repo now, not needed.
    [logTHIS.brd, logTHIS.sch]
2012-12-25 Latest snapshot of schematic. Known bugs: EEPROM wiring needs to be fixed.
    [logTHIS.brd, logTHIS.csv, logTHIS.sch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]
2012-12-27 BOM with 1M EEPROM
    [datalogger - v1 - 1M mouserBOM.ods]
2012-12-27 had I2C bus seperated. Connected it, relaid the PCB, regernated the gerber and drill files.
    I had two I2C buses, one that was (SCK, SDA) and the other being (I2C_CLK, I2C_DAT). Merged
    the two into (I2C_CLK, I2C_DAT) and (just barely) managed to lay out the PCB into a single
    layer.
    [logTHIS.brd, logTHIS.sch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]
2013-01-03 bug fix: 1M EEPROM needs A2 tied hi
    [logTHIS.sch]
2013-01-03 added power jumper to ease single board layout
    [logTHIS.brd, logTHIS.sch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]
2013-01-03 current snapshot of board layout
2013-01-03 whoops, pcb, not schematic
2013-01-03 current logTHIS_schematic
2013-01-06 Updated schematic. - Added ground and Vcc pours. - shifted some lines around to allow for larger pours for GND and VCC - 'Use auxiliary axis as origin' for ploted gerber files. If we don't do this, t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
    [logTHIS.brd, logTHIS.sch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]
2013-01-17 mosfet connected to pin6 of micro
2013-02-01 bug fix: reversed mosfet and had i2c pullups on Vsensor instead of Vcc fixed, rerouted, gcode regenerated
    [logTHIS.brd, logTHIS.sch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]
2013-02-05 updated pcb and schematic
2013-02-05 cosmetic changes to source modified gcode for grbl
2013-02-05 modified ngc to give to grbl
2013-02-06 cleaned up schematic a bit added .ps 'plotted' schematic
    [logTHIS.sch]
2013-02-06 jpeg of schematic for easy viewing and the script that generated it
2013-02-14 temporary: adding arduino menu system interface for integration
2013-02-17 added wear levelling address pointer updates after every data record write. should be a working prototype code. need to test some more
2013-02-17 working prototype hex file
2013-02-22 new logTHIS schematic location and DHT22 board
    [$savepcb.brd, dht22_sensor_schem.brd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]
